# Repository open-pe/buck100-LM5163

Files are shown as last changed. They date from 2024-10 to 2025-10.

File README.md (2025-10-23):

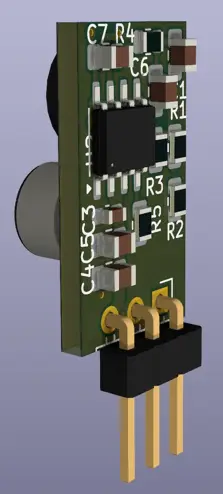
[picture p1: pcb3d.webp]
3D rendering


## Specs

| | |
|---|---|
| Vin  | 6..100 V |
| Vout | 2..20 V  |
| Iout | 0.5 A |
| fsw  | 100 kHz  |

## Feedback Resistor and Indcutor Values

Use the table to find values for Rfb1, Rfb2, Rt, Ra and inductivity for given V_out at ~100khz switching frequency:

| Vout | | Rfb1 | Rfb2 | Rt | Ra (R4) | L |
|---|---|---|---|---|---|---|
| 3.33 | | 390k | 220k | 100k | 470k..715k | 470uH | 
| 3.35 | | 430k | 240k | 100k | 470k..715k | 470uH |
| 11.2 | | 470k | 56k  | 390k | 600k..1.5M | 1.6mH |
| 11.3 | | 430k | 51k  | 390k | 600k..1.5M | 1.6mH |
| 11.3 | | 430k | 50k  | 390k | 600k..1.5M | 1.6mH |

* [Common Resistor Values](https://ch00ftech.com/wp-content/uploads/2012/05/resistorsandcaps.pdf)
* LM218x Excel Tool: [Quickstart Calculator](https://www.ti.com/tool/LM5163-LM5164DESIGN-CALC)

## LM516x features

* [LM5163](https://www.ti.com/lit/ds/symlink/lm5163.pdf) (.5A) LM5164](https://www.ti.com/lit/ds/symlink/lm5164.pdf) (
  1A)
* sync buck with nearly 100% max duty cycle
* 0.725Ω NFET buck switch, 0.34Ω NFET synchronous rectifier
* constant on-time (COT) control architecture
* light-load power saving mode
* 10.5µA no-load input quiescent current
* soft-start, UVLO, thermal shutdown
* PGOOD indicator
* quick start calc: https://www.ti.com/tool/LM5163-LM5164DESIGN-CALC

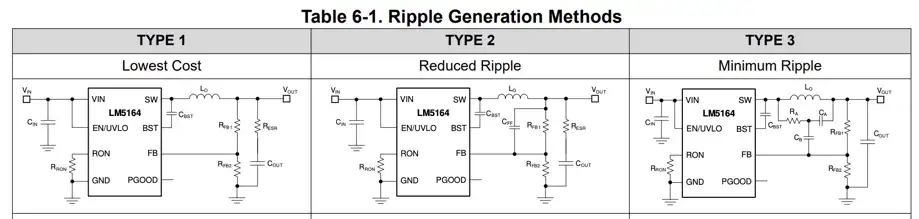
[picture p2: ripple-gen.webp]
Ripple Generation Methods


## Pin-compatible chips

| MPN | Vi  | Io | NFET Rds  | Iq | | Light-Load | |
|---|-----|---|---|---|---|---|---|
| LM5168 | 120 | 0.3  | 1.9/.71Ω  | 10µA  | COT, FPWM or PFM | DEM | [pdf](https://www.ti.com/lit/ds/symlink/lm5169.pdf) |
| LM5169 | 120 | 0.65 | 1.9/.71Ω  | 10µA  | COT, FPWM or PFM | DEM | [pdf](https://www.ti.com/lit/ds/symlink/lm5169.pdf) |
| LM5163 | 100 | 0.5  | .725/.34Ω | 10µA  | COT | DEM | https://www.ti.com/lit/ds/symlink/lm5163.pdf?ts=1731081870545 |
| LM5164 | 100 | 1.0  | .725/.34Ω | 10µA  | COT | DEM | https://www.ti.com/lit/ds/symlink/lm5163.pdf?ts=1731081870545 |
| LM5017 | 100 | 0.6  | | | COT | | |
| LM34927 | | | | | | | |
| *TPP00031/2* | 100 | 0.3  | .7/.3Ω | 125µA | pulse skip | | [pdf](https://static.3peak.com/res/doc/ds/Datasheet_TPP0003x.pdf) |

* [WEBENCH Power Designer]( https://webench.ti.com/power-designer/switching-regulator?base_pn=LM5163&origin=ODS&litsection=features)
* https://webench.ti.com/power-designer/switching-regulator/select

## inductors

requirements:

* Isat well above current limit setting
* Isat decreases with rising temperature
* refer to datasheet [pg 18](https://www.ti.com/lit/ds/symlink/lm5163.pdf#page=18)

| | L | Isat(30%) | DCRmΩ(max) | Q | px(250) | size | Notes |
|---|---|---|---|---|---|---|---|
| MSS1260-124KL | 120uH | 2A | 195 | | 1,33€ | 12mm | LM5163 datasheet |
| Bourns SRN6045-101M  | 100uH | .7A | 494 | 22@796kHz | $,27 | 6mm  | |
| VLS5045EX-101M | 100uH | .7A | 754 | | $,20 | 5mm  | ordered |
| → TY NRS8040T101MJGK | 100uH | 1.1A | 364 | | $,22 | 8mm  | [pdf](https://mm.digikey.com/Volume0/opasdata/d220001/medias/docus/2544/NRS8040T101MJGK_SS.pdf) |
| IFSC3232DBER471M02 | | | | | | | |
| | | | | | | | |

## Other designs using same chip

* https://github.com/90wishpack/LM5164
* https://github.com/FarwayDot/Adapter_PowerSupply_Vigi

# Tests

```
3.3V version:
Vin=15
no load: voltage can oscillate arround 3.3V
750Ω load: voltage stable
short circuit: 50mA Iin
```

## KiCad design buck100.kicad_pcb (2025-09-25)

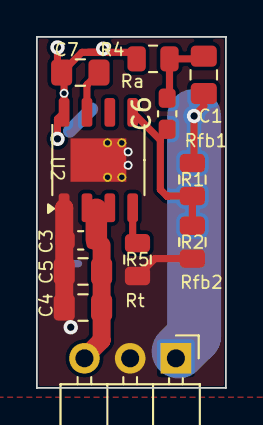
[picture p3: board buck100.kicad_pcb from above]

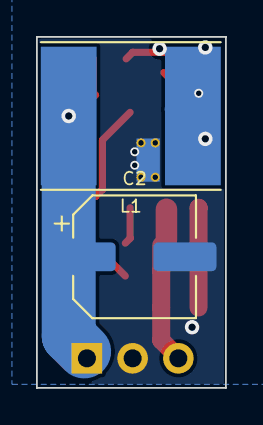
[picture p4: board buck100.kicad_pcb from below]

Board: 2 copper layers, 10.5 x 19.5 mm, 14 parts (2 on the bottom side), 8 nets.

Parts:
C1: 2200 pF, 100 V; C_0805_2012Metric_Pad1.18x1.45mm_HandSolder
C2: 22uF, 25V, X7R; CP_Elec_6.3x5.9
C3: 220nF, 100V, X7S; C_0603_1608Metric_Pad1.08x0.95mm_HandSolder
C4, C5: 1uF, 100V, X7S; C_0805_2012Metric_Pad1.18x1.45mm_HandSolder
C6: 56pF, 50V; C_0603_1608Metric_Pad1.08x0.95mm_HandSolder
C7: 2200 pF, 50 V; C_0805_2012Metric_Pad1.18x1.45mm_HandSolder
J1: Conn_01x03_Male; PinHeader_1x03_P2.54mm_Horizontal
L1: 100uH; L_Taiyo-Yuden_NR-80xx_HandSoldering
R1: 33k; R_0805_2012Metric
R2: 10k; R_0805_2012Metric
R4: R_0805_2012Metric
R5: 100k; R_0805_2012Metric
U2: LM5163DDAR; HSOP-8-1EP_3.9x4.9mm_P1.27mm_EP2.41x3.1mm_ThermalVias

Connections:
+3.3V: C1.2, C2.1, J1.1, L1.2, R1.1
FB: C6.1, R1.2, R2.1, U2.5 (FB)
GND: C2.2, C3.2, C4.2, C5.2, J1.2, R2.2, R5.2, U2.1 (GND), U2.9 (EP)
unnamed: C1.1, C6.2, R4.2
unnamed: C7.1, U2.7 (BST)
unnamed: R5.1, U2.4 (RON)
SW: C7.2, L1.1, R4.1, U2.8 (SW)
VIN: C3.1, C4.1, C5.1, J1.3, U2.2 (VIN), U2.3 (EN/UVLO)

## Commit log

2024-12-05 docs, vias
    [buck100.kicad_pcb, buck100.kicad_sch]
2024-12-19 minor changes
    [buck100.kicad_pcb, buck100.kicad_sch]
2025-09-14 resistor values
2025-09-24 feedback resistors list
    [buck100.kicad_pcb, buck100.kicad_sch]
2025-09-25 bump kicad version
    [buck100.kicad_pcb]
2025-10-29 set drill origin
2026-10-30 Add assembly diagrams for the 3.3 V and 11 V variants
    Footprints drawn from buck100.kicad_pcb with the per-variant values
    (R1, R2, R4, R5, L1) from the README value table inside each box.
    Bottom side (L1, C2) shown mirrored. Generated by
    assembly/gen_assembly_diagram.py (KiCad Python).
